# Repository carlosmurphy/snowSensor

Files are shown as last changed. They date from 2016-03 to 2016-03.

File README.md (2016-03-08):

# snowSensor
Measure snow pack density and stability with allll the sensors

Hardware:
Adafuit Feather M0 datalogger
LSM9DS1 - 9 DOF IMU/temp
HTU21D - humidity/temp
TSL2561 - lux + EO/IR
BMP180 - pressure + altitude/temp
TMP006 - IR infrared temp / die temp
 xxxxxxxx - capacitance

Developed using the Arduino IDE (i'll get away from it some day)
Mechanical work done in SolidWorks
Electrical design done in Circuit Maker (Altium)

Using the Magdwick AHRS scheme to guess the orientation of the sensor
Going to implement an EKF to estimate sensor depth in snow pack
This should be a better option than some mechanical depth sensor IF possible, big if
Otherwise the depth sensor will be a simple encoder with a string connected to it.

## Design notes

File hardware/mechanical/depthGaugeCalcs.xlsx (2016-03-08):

Shaft Length
260 | cm | 102.3622047 | in
cableDiameter
 |  | 0.002 | in
pulley ID
 |  | 0.575 | in
pulleyWidth
 |  | 0.25 | in
rows per layer
125
Layer | 0 | pullyDia | 0.5750 | Distance per turn | 1.8064 | Distance on layer | 225.80 | total distance | 225.80 | in
 | 1 | pullyDia | 0.5770 | Distance per turn | 1.8127 | Distance on layer | 226.59 | total distance | 452.39 | in
 | 2 | pullyDia | 0.5790 | Distance per turn | 1.8190 | Distance on layer | 227.37 | total distance | 679.76 | in

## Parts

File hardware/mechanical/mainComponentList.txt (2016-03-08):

processing/power:
ATmega32u4 - 44QFN
crystal - 8mhz
battery - 1 cell lipo
usb charger - mcp73831/2
power control - spx3819-3.3
power indicator (1) - green LED
activity/readiness indicator (1) - blue LED

sensors:
imu - LSM9DS1
baro - 
thermometer - 
humidity - 
photocell - 
LED for photocell - 
IR sensor+source - 
capacitance - 
resistance? -

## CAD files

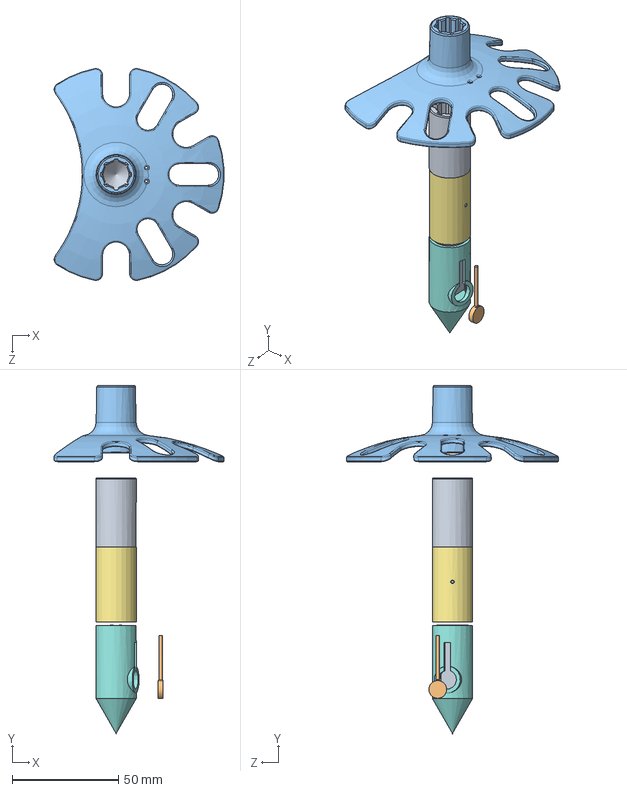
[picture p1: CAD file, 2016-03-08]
hardware/mechanical/ProbeEnd.SLDASM
79.8 x 163.7 x 99.6 mm
sensorBodyTop
HPB-150A-A-L3-5-B
depthAnchor
depthPully
3315C-102-016L
9293K42
sensorBodyMid
sensorBodyLower
pcbOutline x 2

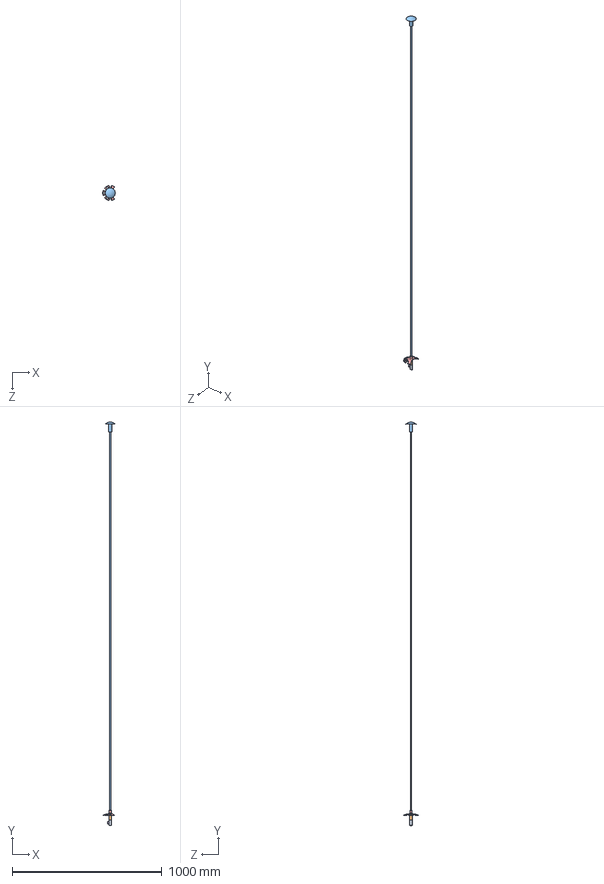
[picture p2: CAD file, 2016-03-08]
hardware/mechanical/AssembledProbe.SLDASM
84.5 x 2700.9 x 99.7 mm
BCAstealth260carbon
sensorBodyTop
HPB-150A-A-L3-5-B
depthAnchor
depthPully
3315C-102-016L
9293K42
sensorBodyMid

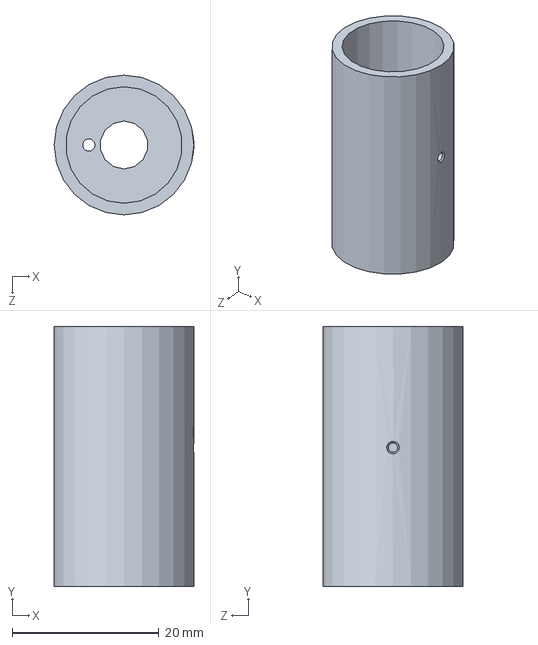
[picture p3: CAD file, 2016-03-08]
hardware/mechanical/sensorBodyMid.SLDPRT
19.1 x 35.4 x 19.1 mm

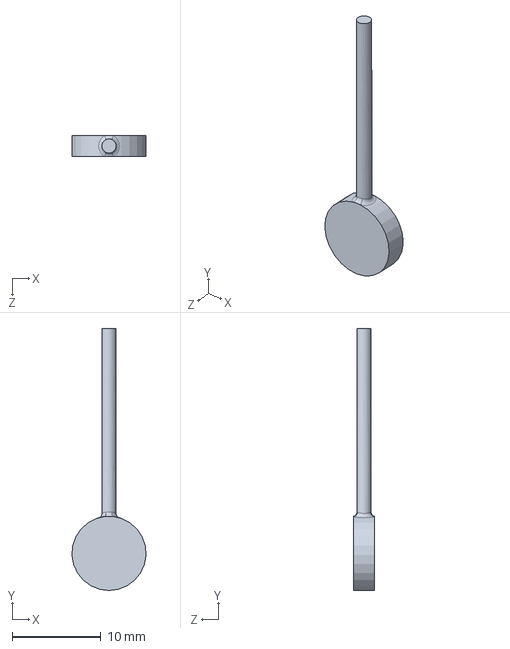
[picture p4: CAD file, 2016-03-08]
hardware/mechanical/HPB-150A-A-L3-5-B.SLDPRT
8.37 x 29.6 x 2.36 mm

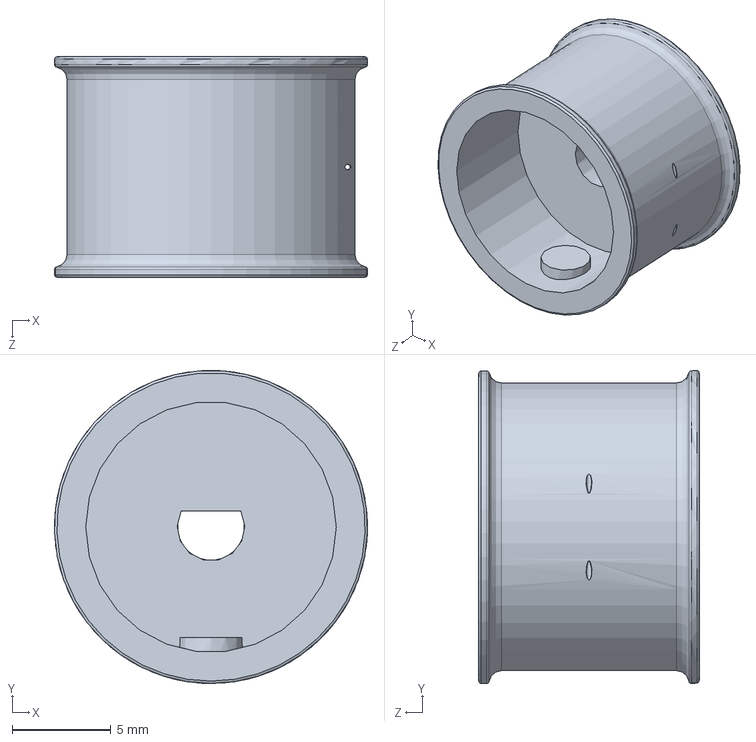
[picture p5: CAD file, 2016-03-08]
hardware/mechanical/depthPully.SLDPRT
15.9 x 15.9 x 11.2 mm

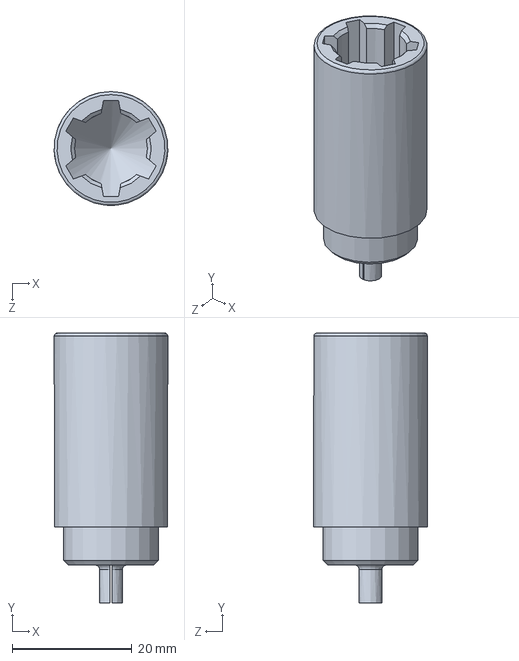
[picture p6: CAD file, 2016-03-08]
hardware/mechanical/sensorBodyTop.SLDPRT
19.0 x 45.2 x 19.1 mm

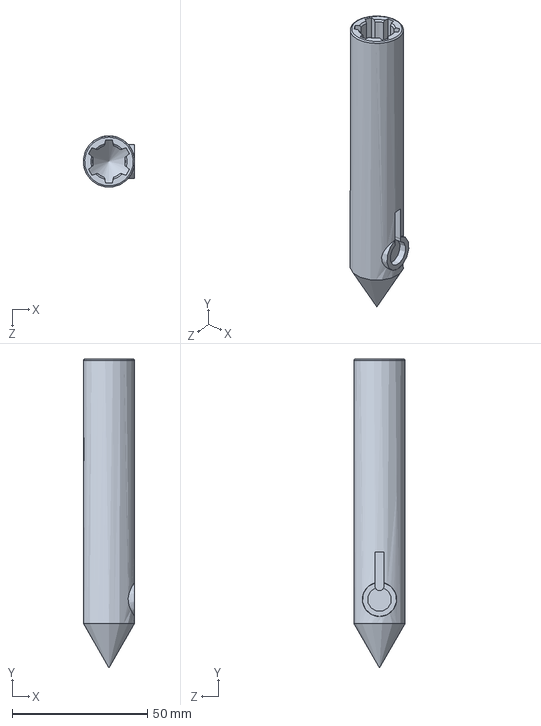
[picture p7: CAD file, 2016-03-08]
hardware/mechanical/sensorBody.SLDPRT
19.0 x 114.3 x 19.1 mm

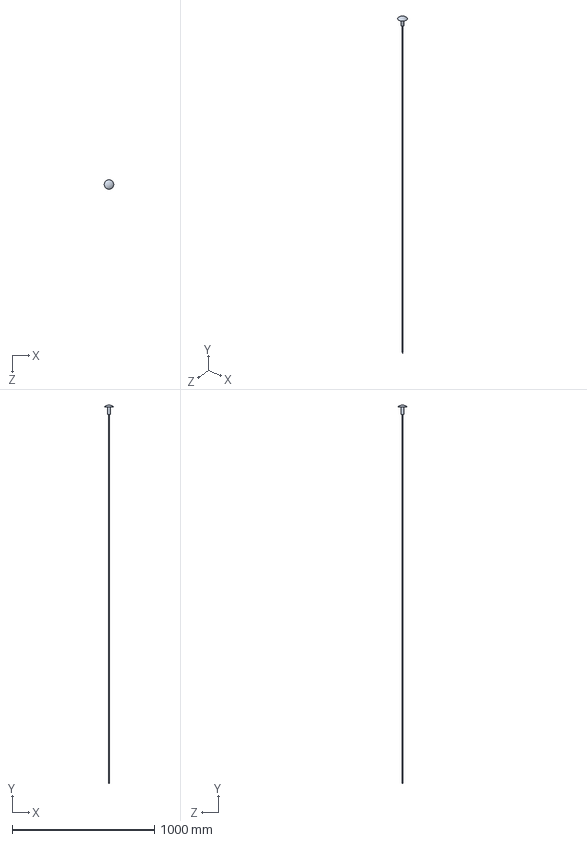
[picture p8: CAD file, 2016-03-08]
hardware/mechanical/BCAprobe.SLDPRT
67.6 x 2667.5 x 67.6 mm

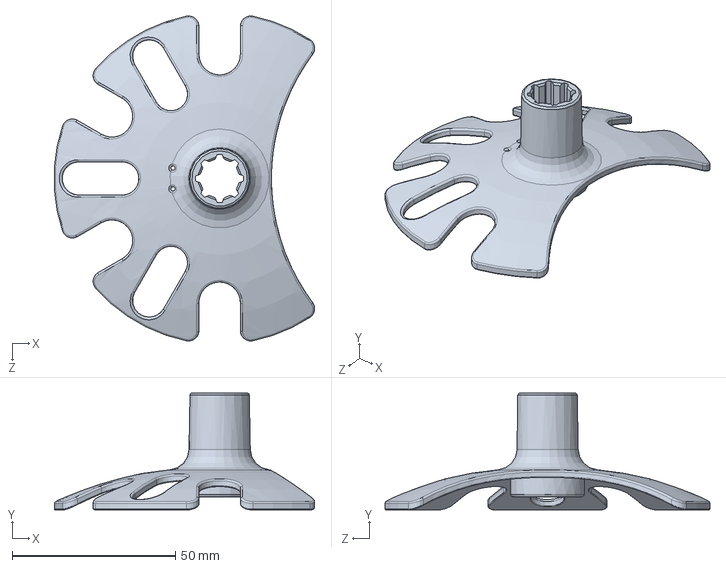
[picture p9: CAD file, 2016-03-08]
hardware/mechanical/depthAnchor.SLDPRT
79.8 x 35.9 x 99.6 mm

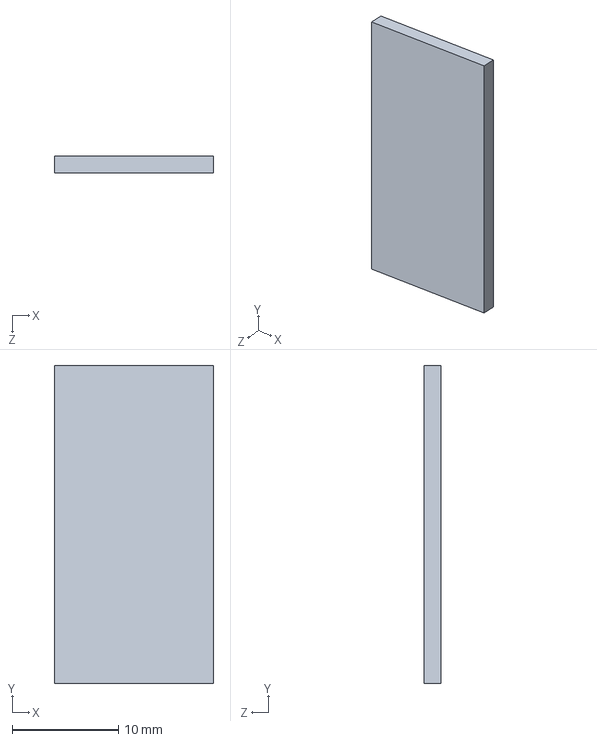
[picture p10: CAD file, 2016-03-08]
hardware/mechanical/pcbOutline.SLDPRT
15.0 x 30.0 x 1.59 mm

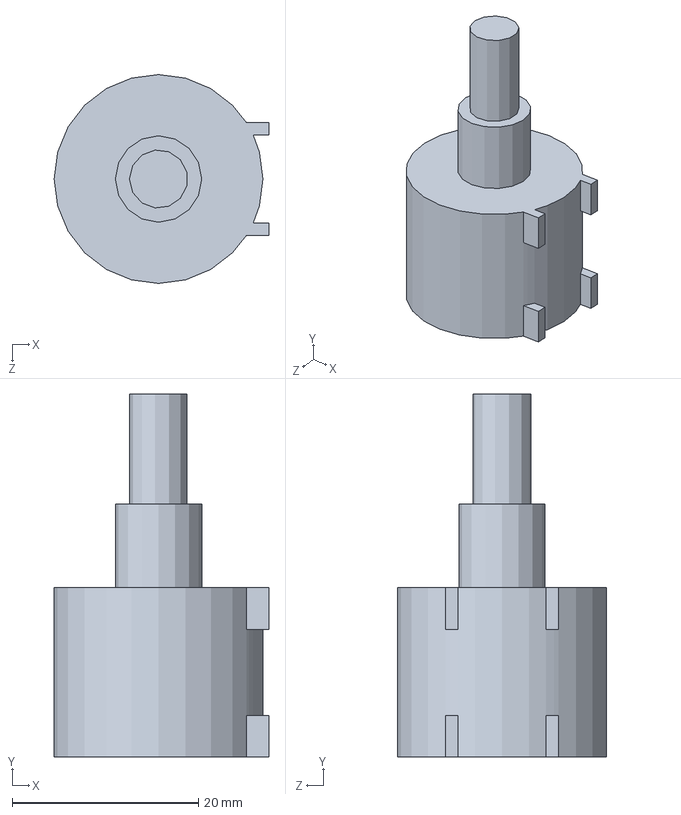
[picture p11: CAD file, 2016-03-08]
hardware/mechanical/3590S-2-103L.SLDPRT
23.0 x 38.9 x 22.4 mm

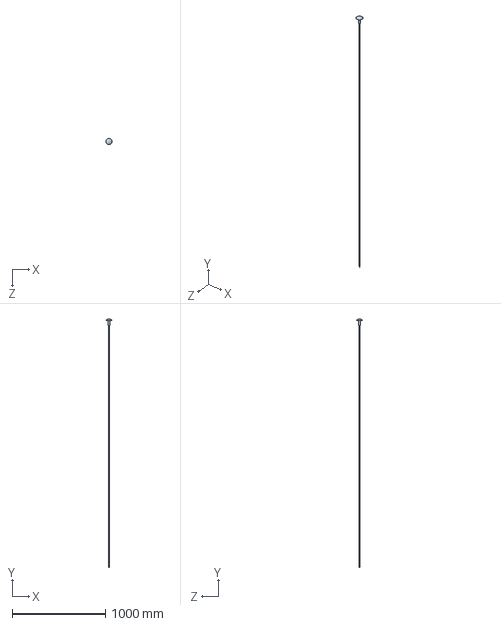
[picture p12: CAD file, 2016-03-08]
hardware/mechanical/BCAstealth260carbon.SLDPRT
67.6 x 2667.5 x 67.6 mm

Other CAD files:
hardware/mechanical/3856A.SLDPRT
hardware/mechanical/3315C-102-016L.SLDPRT
hardware/mechanical/sensorBodyLower.SLDPRT
hardware/mechanical/retractorAnchor.SLDPRT
hardware/mechanical/9293K42.SLDPRT
hardware/mechanical/depthAnchor.STL
hardware/mechanical/depthPully.STL
hardware/mechanical/sensorBody.STL
hardware/mechanical/sensorBodyMid.STL
hardware/mechanical/sensorBodyTop.STL

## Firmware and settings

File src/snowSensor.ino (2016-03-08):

#include <Wire.h>
#include <SPI.h>
#include <SD.h>
#include <SparkFunLSM9DS1.h>
#include <Adafruit_Sensor.h>
#include "Adafruit_TMP006.h"
#include "SparkFunHTU21D.h"
#include <SFE_BMP180.h>
#include <SparkFunTSL2561.h>

//Because the M0 core is stupid...
#define Serial SerialUSB

//pin used by the feather for SS on the SPI bus
#define cardSelect 4

//creating file object to write into the SD card
File logfile;

//////////// Use the LSM9DS1 class to create an object. 9 dof sensor///////////////////////
LSM9DS1 imu;

// global constants for 9 DoF fusion and AHRS (Attitude and Heading Reference System)
#define GyroMeasError PI * (40.0f / 180.0f)       // gyroscope measurement error in rads/s (shown as 3 deg/s)
#define GyroMeasDrift PI * (0.0f / 180.0f)      // gyroscope measurement drift in rad/s/s (shown as 0.0 deg/s/s)
// There is a tradeoff in the beta parameter between accuracy and response speed.
// In the original Madgwick study, beta of 0.041 (corresponding to GyroMeasError of 2.7 degrees/s) was found to give optimal accuracy.
// However, with this value, the LSM9SD0 response time is about 10 seconds to a stable initial quaternion.
// Subsequent changes also require a longish lag time to a stable output, not fast enough for a quadcopter or robot car!
// By increasing beta (GyroMeasError) by about a factor of fifteen, the response time constant is reduced to ~2 sec
// I haven't noticed any reduction in solution accuracy. This is essentially the I coefficient in a PID control sense;
// the bigger the feedback coefficient, the faster the solution converges, usually at the expense of accuracy.
// In any case, this is the free parameter in the Madgwick filtering and fusion scheme.
#define beta sqrt(3.0f / 4.0f) * GyroMeasError   // compute beta
#define zeta sqrt(3.0f / 4.0f) * GyroMeasDrift   // compute zeta, the other free parameter in the Madgwick scheme usually set to a small or zero value
#define Kp 2.0f * 5.0f // these are the free parameters in the Mahony filter and fusion scheme, Kp for proportional feedback, Ki for integral
#define Ki 0.0f

uint32_t count = 0;  // used to control display output rate
uint32_t delt_t = 0; // used to control display output rate
float pitch, yaw, roll, heading;
float deltat = 0.0f;        // integration interval for both filter schemes
uint32_t lastUpdate = 0;    // used to calculate integration interval
uint32_t Now = 0;           // used to calculate integration interval

float ax, ay, az, gx, gy, gz, mx, my, mz; // variables to hold latest sensor data values
float q[4] = {1.0f, 0.0f, 0.0f, 0.0f};    // vector to hold quaternion
float eInt[3] = {0.0f, 0.0f, 0.0f};       // vector to hold integral error for Mahony method
float temperature; //temp of the imu sensor

// Earth's magnetic field varies by location. Add or subtract
// a declination to get a more accurate heading. Calculate
// your's here:
// http://www.ngdc.noaa.gov/geomag-web/#declination
#define DECLINATION -8.58 // Declination (degrees) in Boulder, CO.


////////////////// TMP006 object creation, temp sensor//////////////////////
Adafruit_TMP006 thermopile(0x44); //default address is 0x40
// addr1 pin must be connected to vcc addr0 to gnd
//Adafruit_TMP006 tmp006(0x41);  // start with a diferent i2c address!

///////////////////Create an instance of the humidity sensor/////////////////////
HTU21D humidity; //i2c address 0x40

// //////////////////SFE_BMP180 object, pressure sensor////////////////////
SFE_BMP180 pressure;
double baseline; // baseline pressure


/////////////// Create an SFE_TSL2561 object, light sensor//////////////
SFE_TSL2561 light;
boolean gain;     // Gain setting, 0 = X1, 1 = X16;
unsigned int ms;  // Integration ("shutter") time in milliseconds


////////////////////////////
// Sketch Output Settings //
////////////////////////////
#define PRINT_CALCULATED
//#define PRINT_RAW
#define PRINT_SPEED 2000 // xxx ms between prints

void setup() {

//Starting the Serial Port
Serial.begin(9600);
//built in feather LED pin
 pinMode(8, OUTPUT);

////////////////////////////staring SD card /////////////////////////////////
 pinMode(13, OUTPUT); //don't really know it was in the example?

 // see if the card is present and can be initialized:
 if (!SD.begin(cardSelect)) {
   Serial.println("Card init. failed!");
 }
 char filename[15];
 strcpy(filename, "SENSOR00.TXT");
 for (uint8_t i = 0; i < 100; i++) {
   filename[6] = '0' + i/10;
   filename[7] = '0' + i%10;
   // create if does not exist, do not open existing, write, sync after write
   if (! SD.exists(filename)) {
     break;
   }
 }

 logfile = SD.open(filename, FILE_WRITE);
 if( ! logfile ) {
   Serial.print("Couldnt create ");
   Serial.println(filename);
 }
 Serial.print("Writing to ");
 Serial.println(filename);
 pinMode(13, OUTPUT);                  // twice for some reason, still dont know what pin 13 is
 Serial.println("SD Card Ready!");

//Starting all the sensors

////////////////////// starting the 9 dof sensor ///////////////////
  if (!initLSM9DS1())
  {
    Serial.println("Failed to communicate with LSM9DS1.");
    while (1) //freeze
      ;
  }
  //////////////////////// starting thermopile sensor //////////////////////////////

  // you can also use tmp006.begin(TMP006_CFG_1SAMPLE) or 2SAMPLE/4SAMPLE/8SAMPLE to have
  // lower precision, higher rate sampling. default is TMP006_CFG_16SAMPLE which takes
  // 4 seconds per reading (16 samples)
  if (!thermopile.begin()) {
    Serial.println("No temp006 found");
    while (1); //freeze
  }

  //////////////////////////////// start humidity sensor //////////////////////////////
  humidity.begin();

/////////////////// start pressure sensor /////////////////////////////////////
   if (!pressure.begin()) {
    Serial.println("No BMP180 found");
    while (1); //freeze
  }
  // Get the baseline pressure:
  baseline = getPressure();

////////////////////////// start light sensor ///////////////////////////////////
  // Initialize the SFE_TSL2561 library

  // You can pass nothing to light.begin() for the default I2C address (0x39),
  // or use one of the following presets if you have changed
  // the ADDR jumper on the board:

  // TSL2561_ADDR_0 address with '0' shorted on board (0x29)
  // TSL2561_ADDR   default address (0x39)
  // TSL2561_ADDR_1 address with '1' shorted on board (0x49)

  // For more information see the hookup guide at: https://learn.sparkfun.com/tutorials/getting-started-with-the-tsl2561-luminosity-sensor

  light.begin();
  // Get factory ID from sensor:
  // (Just for fun, you don't need to do this to operate the sensor)

  unsigned char ID;
if (light.getID(ID))
  {
    Serial.print("Got factory ID: 0X");
    Serial.print(ID,HEX);
    Serial.println(", should be 0X5X");
  }
  // Most library commands will return true if communications was successful,
  // and false if there was a problem. You can ignore this returned value,
  // or check whether a command worked correctly and retrieve an error code:
  else
  {
    byte error = light.getError();
    printError(error);
  }

  // The light sensor has a default integration time of 402ms,
  // and a default gain of low (1X).

  // If you would like to change either of these, you can
  // do so using the setTiming() command.

  // If gain = false (0), device is set to low gain (1X)
  // If gain = high (1), device is set to high gain (16X)

  gain = 0;

  // If time = 0, integration will be 13.7ms
  // If time = 1, integration will be 101ms
  // If time = 2, integration will be 402ms
  // If time = 3, use manual start / stop to perform your own integration

  unsigned char time = 2;

  // setTiming() will set the third parameter (ms) to the
  // requested integration time in ms (this will be useful later):

  Serial.println("Set timing...");
  light.setTiming(gain,time,ms);

  // To start taking measurements, power up the sensor:

  Serial.println("Powerup...");
  light.setPowerUp();

/////////////////////////writing first line of the CSV file
writeLog("roll(deg),pitch(deg),yaw(deg),temp,object temp, die temp,humidity, temp, Pressure, altitude (m),EO,IR,Lux");

}

void loop() {

  // make an empty string for assembling the data to log:
  String dataString = "";

  ///////////dumping IMU data ////////////////////////////////////
  if (imu.accelAvailable())
    {
      imu.readAccel();
      ax=imu.calcAccel(imu.ax)-imu.aBias[0]; //convert to G and remove bias
      ay=imu.calcAccel(imu.ay)-imu.aBias[1];
      az=imu.calcAccel(imu.az)-imu.aBias[2];
    }

    // imu.gyroAvailable() returns 1 if new gyroscope
    // data is ready to be read. 0 otherwise.
    if (imu.gyroAvailable())
    {
      imu.readGyro();
      gx=imu.calcGyro(imu.gx)-imu.gBias[0]; //convert to deg/s and remove bias
      gy=imu.calcGyro(imu.gy)-imu.gBias[1];
      gz=imu.calcGyro(imu.gz)-imu.gBias[2];
    }

    // imu.magAvailable() returns 1 if new magnetometer
    // data is ready to be read. 0 otherwise.
    if (imu.magAvailable())
    {
      imu.readMag();
      mx=imu.calcMag(imu.mx); //convert to gauss
      my=imu.calcMag(imu.my);
      mz=imu.calcMag(imu.mz);
    }

  // imu.tempAvailable() returns 1 if new temperature sensor
  // data is ready to be read. 0 otherwise.
  if (imu.tempAvailable())
  {
    imu.readTemp();
    temperature=imu.temperature;
  }

  Now = micros();
  deltat = ((Now - lastUpdate)/1000000.0f); // set integration time by time elapsed since last filter update
  lastUpdate = Now;
  // Sensors x- and y-axes are aligned but magnetometer z-axis (+ down) is opposite to z-axis (+ up) of accelerometer and gyro!
  // This is ok by aircraft orientation standards!
  // Pass gyro rate as rad/s
   MadgwickQuaternionUpdate(ax, ay, az, gx*PI/180.0f, gy*PI/180.0f, gz*PI/180.0f, mx, my, mz);
 //MahonyQuaternionUpdate(ax, ay, az, gx*PI/180.0f, gy*PI/180.0f, gz*PI/180.0f, mx, my, mz);

   roll = getRoll(); //getting the Euler angles from the quaternion
   pitch = getPitch();
   yaw = getYaw();

   roll  *= 180.0f / PI;
   pitch *= 180.0f / PI;
   yaw   *= 180.0f / PI;
   yaw   += DECLINATION; // compensate for the Declination

  //adding data to the string for writing to the SD card
  dataString += String(int(1000*roll));
  dataString += ",";
  dataString += String(int(1000*pitch));
  dataString += ",";
  dataString += String(int(1000*yaw));
  dataString += ",";
  dataString += String(int(temperature));
  dataString += ",";

////////////////////dumping thermopile data //////////////////////////////////////////////
// Grab temperature measurements and print them.
  float objt = thermopile.readObjTempC(); //object temp
  float diet = thermopile.readDieTempC(); //sensor internal temp

    //adding data to the string for writing to the SD card
  dataString += String(int(1000*objt));
  dataString += ",";
  dataString += String(int(1000*diet));
  dataString += ",";

 //////////////////////////////////////dumping humidity data///////////////////////////////////
 float humd = humidity.readHumidity();
 float temp = humidity.readTemperature();

  //adding data to the string for writing to the SD card
  dataString += String(int(1000*humd));
  dataString += ",";
  dataString += String(int(1000*temp));
  dataString += ",";

 //if humd or temp = 999 then there is a CRC error
 //if humd or temp = 998 if the sensor is not detected

 //////////////////////////////////////dumping pressure data ///////////////////////////////////
 double a,P;

  // Get a new pressure reading:

  P = getPressure();

  // Show the relative altitude difference between
  // the new reading and the baseline reading:

  a = pressure.altitude(P,baseline);

  //adding data to the string for writing to the SD card
  dataString += String(int(1000*P));
  dataString += ",";
  dataString += String(int(1000*a));
  dataString += ",";

  //////////////////////////////dumping light data ////////////////////////////////////////////////
  // Wait between measurements before retrieving the result
  // (You can also configure the sensor to issue an interrupt
  // when measurements are complete)

  // This sketch uses the TSL2561's built-in integration timer.
  // You can also perform your own manual integration timing
  // by setting "time" to 3 (manual) in setTiming(),
  // then performing a manualStart() and a manualStop() as in the below
  // commented statements:

  // ms = 1000;
  // light.manualStart();
  //delay(ms);
  // light.manualStop();

  // Once integration is complete, we'll retrieve the data.

  // There are two light sensors on the device, one for visible light
  // and one for infrared. Both sensors are needed for lux calculations.

  unsigned int data0, data1; //IR and EO intensity (or something)
  double lux;    // Resulting lux value
  boolean good;  // True if neither sensor is saturated
  // Retrieve the data from the device:
  if (light.getData(data0,data1))
  {
    // getData() returned true, communication was successful

    // To calculate lux, pass all your settings and readings
    // to the getLux() function.

    // The getLux() function will return 1 if the calculation
    // was successful, or 0 if one or both of the sensors was
    // saturated (too much light). If this happens, you can
    // reduce the integration time and/or gain.
    // For more information see the hookup guide at: https://learn.sparkfun.com/tutorials/getting-started-with-the-tsl2561-luminosity-sensor

    // Perform lux calculation:

    good = light.getLux(gain,ms,data0,data1,lux);

    //adding data to the string for writing to the SD card
    dataString += String(int(data0*1000));
    dataString += " , ";
    dataString += String(int(data1*1000));
    dataString += " , ";
    dataString += String(int(lux*1000));
    dataString += " , ";

    }
    else
    {
      // getData() returned false because of an I2C error, inform the user.

      byte error = light.getError();
      printError(error);
    }
/////////////////////printingToSerial///////////////////////////////////////////////////////////////////////////
// Serial print and/or display at 0.5 s rate independent of data rates
delt_t = millis() - count;
if (delt_t > 500) { // update once per half-second independent of read rate
  ///////////////////AHRS RESULTS

    Serial.print("ax = "); Serial.print((int)1000*ax);
    Serial.print(" ay = "); Serial.print((int)1000*ay);
    Serial.print(" az = "); Serial.print((int)1000*az); Serial.println(" mg");
    Serial.print("gx = "); Serial.print( gx, 2);
    Serial.print(" gy = "); Serial.print( gy, 2);
    Serial.print(" gz = "); Serial.print( gz, 2); Serial.println(" deg/s");
    Serial.print("mx = "); Serial.print( (int)1000*mx);
    Serial.print(" my = "); Serial.print( (int)1000*my);
    Serial.print(" mz = "); Serial.print( (int)1000*mz); Serial.println(" mG");

    Serial.print("temperature = "); Serial.println(temperature, 2);

    Serial.print("Yaw, Pitch, Roll: ");
    Serial.print(yaw, 2);
    Serial.print(", ");
    Serial.print(pitch, 2);
    Serial.print(", ");
    Serial.println(roll, 2);

    Serial.print("q0 = "); Serial.print(q[0]);
    Serial.print(" qx = "); Serial.print(q[1]);
    Serial.print(" qy = "); Serial.print(q[2]);
    Serial.print(" qz = "); Serial.println(q[3]);

    Serial.print("filter rate = "); Serial.println(1.0f/deltat, 1);
  ///////////////////temp

  Serial.print("Object Temperature: "); Serial.print(objt); Serial.println("*C");
  Serial.print("Die Temperature: "); Serial.print(diet); Serial.println("*C");

  //////////////////humidity

  Serial.print(" Temperature:");
  Serial.print(temp, 1);
  Serial.print("C");
  Serial.print(" Humidity:");
  Serial.print(humd, 1);
  Serial.print("%");
  Serial.println();

  ///////////////////pressure

  Serial.print("relative altitude: ");
  if (a >= 0.0) Serial.print(" "); // add a space for positive numbers
  Serial.print(a,1);
  Serial.print(" meters, ");
  Serial.print("Pressure: ");
  Serial.print(P);
  Serial.println("mbars");

  /////////////////////light

  Serial.print("EO?: ");
  Serial.print(data0);
  Serial.print(" IR?: ");
  Serial.print(data1);

  Serial.print(" lux: ");
  Serial.print(lux);
  if (good) Serial.println(" (good)"); else Serial.println(" (BAD)");



count = millis(); //recording when the last print was made
}

writeLog(dataString); //Writing alllllllllllll the data to the sd card

}//end of loop//////////////////////////////////////////////////////////////////////////////////////////////////////////////////////////////////////////////////////////////////

void writeLog(String dataz) //writes to the log file and flashes the LED on while doing it
{
digitalWrite(8, HIGH); //LED on for the writing to the card
logfile.println(dataz);
logfile.flush();       //Force write everything to the SD card
digitalWrite(8, LOW);  //LED off after the write is finished
}

//////////////////////////////////// LSM9DS1 sensor settings/////////////////////////////////////////////
uint16_t initLSM9DS1()
{
  setupDevice(); // Setup general device parameters
  setupGyro(); // Set up gyroscope parameters
  setupAccel(); // Set up accelerometer parameters
  setupMag(); // Set up magnetometer parameters
  setupTemperature(); // Set up temp sensor parameter

  return imu.begin();
}

void setupDevice()
{
  // [commInterface] determines whether we'll use I2C or SPI
  // to communicate with the LSM9DS1.
  // Use either IMU_MODE_I2C or IMU_MODE_SPI
  imu.settings.device.commInterface = IMU_MODE_I2C;

  // SDO_XM and SDO_G are both pulled high, so our addresses are:

  // [mAddress] sets the I2C address or SPI CS pin of the
  // LSM9DS1's magnetometer.
  imu.settings.device.mAddress = 0x1E; // Would be 0x1C if SDO_M is LOW
  // [agAddress] sets the I2C address or SPI CS pin of the
  // LSM9DS1's accelerometer/gyroscope.
  imu.settings.device.agAddress = 0x6B; // Would be 0x6A if SDO_AG is LOW
}

void setupGyro()
{
  // [enabled] turns the gyro on or off.
  imu.settings.gyro.enabled = true;  // Enable the gyro
  // [scale] sets the full-scale range of the gyroscope.
  // scale can be set to either 245, 500, or 2000
  imu.settings.gyro.scale = 245; // Set scale to +/-245dps
  // [sampleRate] sets the output data rate (ODR) of the gyro
  // sampleRate can be set between 1-6
  // 1 = 14.9    4 = 238
  // 2 = 59.5    5 = 476
  // 3 = 119     6 = 952
  imu.settings.gyro.sampleRate = 3; // 59.5Hz ODR
  // [bandwidth] can set the cutoff frequency of the gyro.
  // Allowed values: 0-3. Actual value of cutoff frequency
  // depends on the sample rate. (Datasheet section 7.12)
  imu.settings.gyro.bandwidth = 0;
  // [lowPowerEnable] turns low-power mode on or off.
  imu.settings.gyro.lowPowerEnable = false; // LP mode off
  // [HPFEnable] enables or disables the high-pass filter
  imu.settings.gyro.HPFEnable = true; // HPF disabled
  // [HPFCutoff] sets the HPF cutoff frequency (if enabled)
  // Allowable values are 0-9. Value depends on ODR.
  // (Datasheet section 7.14)
  imu.settings.gyro.HPFCutoff = 1; // HPF cutoff = 4Hz
  // [flipX], [flipY], and [flipZ] are booleans that can
  // automatically switch the positive/negative orientation
  // of the three gyro axes.
  imu.settings.gyro.flipX = false; // Don't flip X
  imu.settings.gyro.flipY = false; // Don't flip Y
  imu.settings.gyro.flipZ = false; // Don't flip Z
}

void setupAccel()
{
  // [enabled] turns the acclerometer on or off.
  imu.settings.accel.enabled = true; // Enable accelerometer
  // [enableX], [enableY], and [enableZ] can turn on or off
  // select axes of the acclerometer.
  imu.settings.accel.enableX = true; // Enable X
  imu.settings.accel.enableY = true; // Enable Y
  imu.settings.accel.enableZ = true; // Enable Z
  // [scale] sets the full-scale range of the accelerometer.
  // accel scale can be 2, 4, 8, or 16
  imu.settings.accel.scale = 8; // Set accel scale to +/-8g.
  // [sampleRate] sets the output data rate (ODR) of the
  // accelerometer. ONLY APPLICABLE WHEN THE GYROSCOPE IS
  // DISABLED! Otherwise accel sample rate = gyro sample rate.
  // accel sample rate can be 1-6
  // 1 = 10 Hz    4 = 238 Hz
  // 2 = 50 Hz    5 = 476 Hz
  // 3 = 119 Hz   6 = 952 Hz
  imu.settings.accel.sampleRate = 1; // Set accel to 10Hz.
  // [bandwidth] sets the anti-aliasing filter bandwidth.
  // Accel cutoff freqeuncy can be any value between -1 - 3.
  // -1 = bandwidth determined by sample rate
  // 0 = 408 Hz   2 = 105 Hz
  // 1 = 211 Hz   3 = 50 Hz
  imu.settings.accel.bandwidth = 0; // BW = 408Hz
  // [highResEnable] enables or disables high resolution
  // mode for the acclerometer.
  imu.settings.accel.highResEnable = false; // Disable HR
  // [highResBandwidth] sets the LP cutoff frequency of
  // the accelerometer if it's in high-res mode.
  // can be any value between 0-3
  // LP cutoff is set to a factor of sample rate
  // 0 = ODR/50    2 = ODR/9
  // 1 = ODR/100   3 = ODR/400
  imu.settings.accel.highResBandwidth = 0;
}
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

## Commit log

2016-03-06 First commit
    all the sensor libraries (plus one) and the first commit of the code
2016-03-06 all sensors working and reporting together
    got all the sensors working, most was hardware work pulling off extra
    pull ups, though the tmp006 and htu21d were sharing an address so the
    tmp006 had to get rewired to 0x44
2016-03-08 AHRS + data logging working, removed libraries
    Removed the libraries because that was a shit way to track them when
    using the Arudino IDE, ill figure something out later. Need to get away
    from the arduino IDE. The data logging is working, printing to SD does
    NOT work from floats or doubles only ints i guess.
    [AHRStest.ino, snowSensor.ino]
2016-03-08 added mech, organized
    added all the mechanical files and organized the software from the
    hardware and the mech from the soon to be electrical
    [3315C-102-016L.SLDPRT, 3590S-2-103L.SLDPRT, 3856A.SLDPRT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]
